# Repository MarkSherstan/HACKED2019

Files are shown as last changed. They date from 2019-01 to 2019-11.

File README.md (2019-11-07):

**Checkout the latest updates to the project [here!](https://github.com/EricDavidWells/Realtime-Force-Myography)**

# HACKED2019
Designed and programmed in collaboration with [Eric Wells](https://github.com/Rico5678).

## Inspiration
Gesture control is becoming a popular technique integrated into the growing area of virtual reality and rehabilitation. The popular Myo Armband achieved this using Electromyography (EMG) sensors placed on the forearm. However, this device was recently discontinued from production, leaving a gap in the marketplace.

## What it does
We achieved the same result as the Myo Armband, using a unique method involving Force Sensitive Resistors (FSR's) rather than the expensive EMG sensors. These sensors are much cheaper compared to EMG sensors. They are wrapped around the users forearm and measure pressure changes resulting from different muscle configurations. We use a desktop robotic arm in order to demonstrate the gesture control.

## How we built it
This was entirely constructed in the 24 hour time limit at the hackathon. This included:

* Hardware design and construction
* Mechanical design and construction
* Machine learning algorithm design and implementation
* Implementation of trained model onto functioning hardware
* All software involved in reading and mapping sensor data

## Challenges we ran into
* Non-repatability in the FSR sensors due to the compliant wristband used caused for many retraining sessions to be required

## Accomplishments that I'm proud of
* Successfully classify 4 different gesture controls
* Successfully control a 3 degree of freedom (DOF) robotic arm

## What I learned
How to train and design various classifiers in MATLAB, and how to export the trained model for implementation on real-time hardware.

## What's next for Gesture Controlled Desktop Robotic Arm
Cable management and a more robustly designed mechanical wristband would allow for better repeatability, and likely more classification options.

## Built With
* C++
* Arduino
* MATLAB
* hardware
* machine-learning
* SVM
* human-computer-interaction

## Classification Labels
* 0 --> relax
* 1 --> extension
* 2 --> flexion
* 3 --> fist

## Photo
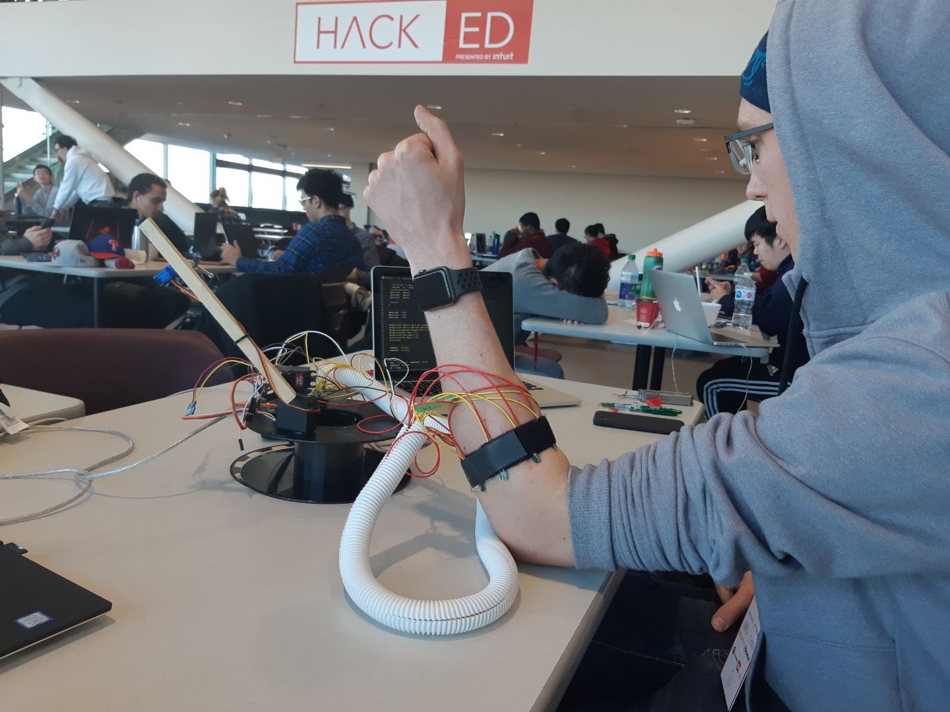
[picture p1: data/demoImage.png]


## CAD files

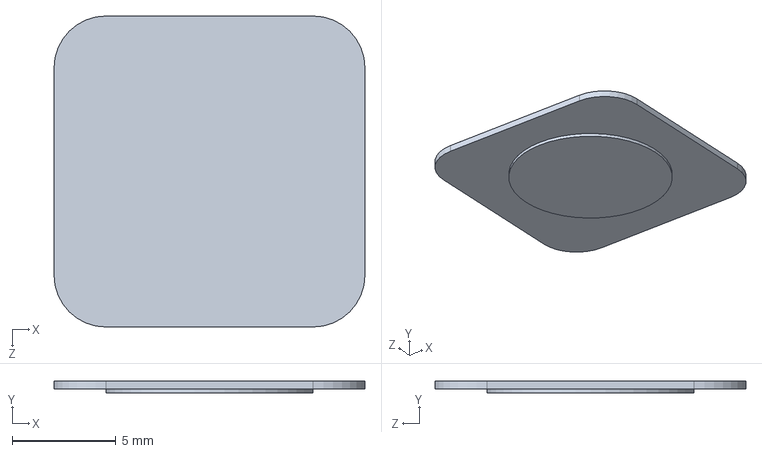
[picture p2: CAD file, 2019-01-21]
data/FSR_Mount.SLDPRT
15.0 x 0.6 x 15.0 mm

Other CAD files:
data/FSR_Mount.STL

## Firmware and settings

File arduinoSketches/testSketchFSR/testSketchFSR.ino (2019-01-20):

#include <Servo.h>
#include <Wire.h>

Servo Shoulder;
Servo Elbow;
Servo Hand;

double accelPitch, accelRoll;
long acc_x, acc_y, acc_z;
long scaleFactor = 8192; // 2g --> 16384 , 4g --> 8192 , 8g --> 4096, 16g --> 2048
double accel_x, accel_y, accel_z;

int Shoulderpos = 1200;
int Elbowpos = 1200;
int Handpos = 3000;

// Declare some variables
const int FSR_PIN[] = {0, 1, 2, 3, 4, 5, 6, 7};

const float VCC = 4.98;
const float R_DIV = 5100.0;

int fsrADC;
float force[8];
float fsrV;
float fsrR;
float fsrG;

String label = "foo\n";
String incomingString;
int dataCount = 0;

int y;

void setup(){
  // Set up serial and pin mode
  Serial.begin(115200);
  Serial.setTimeout(3);
  for (int i=0;i<8;i++){
  pinMode(FSR_PIN[i], INPUT);
  }

  Shoulder.attach(5);
  Elbow.attach(4);
  Hand.attach(11);

  Shoulder.writeMicroseconds(Shoulderpos);
  Elbow.writeMicroseconds(Elbowpos);
  Hand.writeMicroseconds(Handpos);

  setup_mpu_6050_registers();
//
//  pinMode(14, OUTPUT);
//  pinMode(15, OUTPUT);
//  digitalWrite(14, LOW);
//  digitalWrite(15, HIGH);
}


void loop(){
  // Read the raw acc data from MPU-6050
  read_mpu_6050_data();

  // Convert acceleration to g force
  accel_x = (double)acc_x / (double)scaleFactor;
  accel_y = (double)acc_y / (double)scaleFactor;
  accel_z = (double)acc_z / (double)scaleFactor;

  // Find pitch and roll from accelerometer
  accelPitch = atan2(accel_y, accel_z) * RAD_TO_DEG;
  accelRoll = atan2(accel_x, accel_z) * RAD_TO_DEG;
//Serial.println(accelPitch);

  // Map servo value
//  Elbowpos = map(accelPitch,0,-180,500,3000);

  if (accelPitch >= -80){
    Elbowpos = 1150;
  }
  else{
    Elbowpos = 2650;
  }

if (Serial.available() > 0) {
                // read the incoming byte:
  incomingString = Serial.readString();
    if (incomingString.toInt() > 20){
      dataCount = incomingString.toInt();
    }
    else if (incomingString == "a\n") {
      dataCount = 1;
    }
    else if (incomingString.startsWith("s") == true){
      incomingString.remove(0,1);
      y = incomingString.toInt();
    }
    else {
       label = incomingString;
    }
  }

   if (y == 1){
     Shoulderpos += 1;
   }
   else if (y == 2){
     Shoulderpos -= 1;
   }
  if(y == 3){
    Handpos += 1;
  }
  else if(y == 0){
    Handpos -= 1;
//    Elbowpos = 1200;
//    Shoulderpos = 1200;
  }
//  else if(y == 1){
//    Elbowpos += 1;
//  }
//  else if (y == 2){
//    Elbowpos -= 1;
//  }

//  Serial.print(Shoulderpos);
//  Serial.print('\t');
//  Serial.print(Elbowpos);
//  Serial.print('\t');
//  Serial.print(Handpos);
//  Serial.print('\n');

  Shoulderpos = constrain(Shoulderpos, 500, 2000);
  Elbowpos = constrain(Elbowpos, 500, 2000);
  Handpos = constrain(Handpos, 1000, 3000);

  Shoulder.writeMicroseconds(Shoulderpos);
  Elbow.writeMicroseconds(Elbowpos);
  Hand.writeMicroseconds(Handpos);

while (dataCount > 0){
  for (int i=0; i<8;i++){
      // Read pin
    fsrADC = analogRead(FSR_PIN[i]);

    // Use ADC reading to calculate voltage:
    fsrV = fsrADC * VCC / 1023.0;

    // Use voltage and static resistor value to calculate FSR resistance:
    fsrR = ((VCC - fsrV) * R_DIV) / fsrV;

    // Guesstimate force based on slopes in figure 3 of FSR datasheet (conductance):
    fsrG = 1.0 / fsrR;

    // Break parabolic curve down into two linear slopes:
    if (fsrR <= 600)
      force[i] = (fsrG - 0.00075) / 0.00000032639;
    else
      force[i] =  fsrG / 0.000000642857;
    }

float aveforce = 0;
  // Display data [in grams] and add small pause
    for (int i=0; i<8; i++){
        Serial.print(force[i],1);
        Serial.print(',');
        aveforce += force[i];
    }
    aveforce = aveforce/8;
    Serial.print(aveforce,1);
    Serial.print(',');
    Serial.print(label);
//    Serial.println();

    dataCount -= 1;
}
}


void read_mpu_6050_data() {
  //Subroutine for reading the raw accelerometer data
  Wire.beginTransmission(0x68);
  Wire.write(0x3B);
  Wire.endTransmission();
  Wire.requestFrom(0x68, 6);

  // Read data
  while (Wire.available() < 6);
  acc_x = Wire.read() << 8 | Wire.read();
  acc_y = Wire.read() << 8 | Wire.read();
  acc_z = Wire.read() << 8 | Wire.read();
}


void setup_mpu_6050_registers() {
  //Activate the MPU-6050
  Wire.beginTransmission(0x68);
  Wire.write(0x6B);
  Wire.write(0x00);
  Wire.endTransmission();

  //Configure the accelerometer
  Wire.beginTransmission(0x68);
  Wire.write(0x1C);
  Wire.write(0x08); // 2g --> 0x00, 4g --> 0x08, 8g --> 0x10, 16g --> 0x18
  Wire.endTransmission();
}

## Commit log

2019-01-19 Rearrange formula to make more sense. Took out extra serial.print data.
2019-01-20 Added force average and data
    [1914_Bourk.csv]
2019-01-20 csv file type change
    [1914_Bourk.csv]
2019-01-20 Added data with 10 classes
    [2042_Bourk.csv]
2019-01-20 New data, training upgrades
    [2244_RicoTest.csv, 2244_RicoTrain.csv, 2314_RicoTest.csv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]
2019-01-20 Removed normalization, updated real time method
    [0223_MarkTrain.csv]
2019-01-20 Updated Real Time Script and Data
    [0443-MarkTrain.csv, 0443_MarkTrain.csv, 0503_Eric.csv]
2019-01-20 Add accelerometer
2019-01-20 Data, Windowing
    [0605_Mark.csv]
2019-01-20 New Data Dump
    [1005_Squid.csv, 1029_Mark.csv, 1111_RicoFinal.csv]
2019-01-20 IMU Mapping Added
2019-01-21 Final data and model
    [1305_RicoPreFinalPrez.csv, FINAL.csv, GrandFinal.csv]
2019-01-21 Commit CAD files for surface mounts
    [FSR_Mount.SLDPRT, FSR_Mount.STL]
